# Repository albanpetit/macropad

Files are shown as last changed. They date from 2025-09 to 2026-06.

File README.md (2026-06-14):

# Makerpad

A fully open-source macropad built from scratch — custom PCB, 3D-printed enclosure, and embedded firmware. 20 programmable keys, two rotary encoders, a 2" color display driven by LVGL, and 22 addressable RGB LEDs, all running on an RP2040.

Everything is designed to be reproducible: order the PCB, print the case, flash the firmware, and configure your keymap via a JSON file.

---

## What's inside

| Directory | Description |
|---|---|
| [`ecad/`](ecad/README.md) | KiCad schematic + PCB, BOM, custom footprints |
| [`mcad/`](mcad/README.md) | STEP files for the enclosure |
| [`fw/`](fw/README.md) | PlatformIO firmware (C++, RP2040) |
| `doc/` | Datasheets, iBOM, schematic PDF |

---

## Hardware at a glance

| Component | Part |
|---|---|
| MCU | RP2040 (LQFN-56), 133 MHz, 264 KB RAM |
| Flash | W25Q128JVP — 16 MB SPI |
| Display | HS20HS072RX — 2" 240×320 ST7789V2-HSD SPI |
| RGB LEDs | WS2812B-2020 × 22 — addressable, 5V |
| Keys | 4 cols × 5 rows = 20 keys |
| Encoders | PEC12R-4225F-S0024 × 2 — 24 PPR + push |
| Connectivity | USB-C (HID keyboard + consumer control) |

---

## Roadmap

- [x] Layer switching via encoder
- [x] Volume control with speaker/mic toggle
- [ ] Macro sequence support
- [ ] Per-key LED color from config
- [ ] OTA config update via USB mass storage

---

## Contributing

See [CONTRIBUTING.md](CONTRIBUTING.md) for the commit convention, scope definitions, and contribution guidelines.

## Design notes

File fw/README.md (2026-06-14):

# Firmware

Built with [PlatformIO](https://platformio.org/) targeting the RP2040. Keys, layers and LED settings live in a JSON config file on LittleFS — no recompilation needed to remap keys.

---

## Getting started

```bash
pio run -e pico -t upload      # Flash firmware
pio run -e pico -t uploadfs    # Flash default config
pio device monitor -e pico     # Serial monitor (115200 baud)
```

---

## Key configuration

Config is stored in `data/config.json` and loaded from LittleFS at boot.

```json
{
  "brightness": 80,
  "active_layer": 0,
  "layers": [
    {
      "name": "Default",
      "color": [0, 100, 255],
      "keys": [
        { "type": "key",      "code": 4   },
        { "type": "consumer", "code": 233 },
        { "type": "key",      "code": 0   }
      ]
    }
  ]
}
```

Each layer holds 20 key definitions (row-major, 4 cols × 5 rows).

| Key type | Description |
|---|---|
| `key` | Standard HID keycode |
| `consumer` | Consumer control (media, volume) |
| `macro` | Sequence of keycodes *(planned)* |

---

## Controls

| Control | Action |
|---|---|
| Encoder 0 rotate | Navigate layers |
| Encoder 0 press | Activate selected layer |
| Encoder 1 rotate | Volume up/down |
| Encoder 1 press | Mute |
| Encoder 1 long press (600 ms) | Toggle speaker / mic mode |

---

## Architecture

```
fw/src/
├── main.cpp              # Entry point, main loop
├── lv_conf.h             # LVGL compile-time config
├── config/
│   ├── config.h          # Pin definitions, build constants
│   └── keymap.h          # KeyDef, Layer types + default keymap
├── hal/
│   ├── matrix.h/.cpp     # Key matrix scanning (4×5, debounce)
│   ├── encoder.h/.cpp    # Rotary encoder via interrupt
│   ├── leds.h/.cpp       # WS2812B via NeoPixel
│   └── display.h/.cpp    # ST7789V2-HSD driver + LVGL flush bridge
├── hid/
│   └── hid.h/.cpp        # USB HID (keyboard + consumer control)
├── storage/
│   └── storage.h/.cpp    # LittleFS + ArduinoJson config persistence
└── ui/
    └── ui.h/.cpp         # LVGL single-screen layer list
```

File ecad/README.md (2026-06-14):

# ECAD

PCB design for the Makerpad — schematic and layout done in [KiCad](https://www.kicad.org/).

---

## Files

| File / Directory | Description |
|---|---|
| `ecad.kicad_pro` | KiCad project root |
| `ecad.kicad_sch` | Top-level schematic |
| `switches.kicad_sch` | Key matrix sub-sheet |
| `leds.kicad_sch` | LED chain sub-sheet |
| `ecad.kicad_pcb` | PCB layout |
| `library.pretty/` | Custom footprints (RP2040, WS2812B-2020, encoders…) |
| `3d-models/` | STEP files for 3D preview |
| `ecad-backups/` | KiCad auto-backups |

Exported outputs live in `doc/`:

| Output | Description |
|---|---|
| `doc/bom.xlsx` / `bom.pdf` | Bill of materials |
| `doc/schematic.pdf` | Full schematic PDF |
| `doc/ibom/ibom.html` | Interactive BOM (open in browser) |
| `doc/ecad-export/` | Gerbers and drill files |
| `doc/datasheet/` | Datasheets for key components |

---

## Opening the project

```bash
kicad ecad.kicad_pro
```

Requires KiCad 8 or later. All symbols and footprints are embedded or resolved via `sym-lib-table` and `fp-lib-table` — no external library setup needed.

---

## Interactive BOM

Open `doc/ibom/ibom.html` in any browser. Click a component to highlight its position on the board — useful when soldering.

---

## Ordering the PCB

1. Use the Gerbers in `doc/ecad-export/` and upload them to your preferred fabricator (JLCPCB, PCBWay, OSHPark…).
2. Recommended specs: 2-layer, 1.6 mm FR4, HASL or ENIG finish, 0.2 mm min trace/space.
3. Cross-reference the BOM (`doc/bom.xlsx`) for part numbers and quantities.

---

## Custom footprints (`library.pretty/`)

| Footprint | Component |
|---|---|
| `QFN-56-1EP_7x7mm_P0.4mm` | RP2040 |
| `LED_WS2812B-2020_PLCC4_2.0x2.0mm` | WS2812B-2020 RGB LED |
| `Crystal_SMD_Abracon_ABM8G-4Pin_3.2x2.5mm` | 12 MHz crystal |
| `Hirose_FH12-12S-0.5SH` | 0.5 mm FPC connector (display) |
| `PinHeader_2x05_P1.27mm_Vertical_SMD` | SWD debug header |

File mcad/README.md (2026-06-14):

# MCAD

3D models for the Makerpad enclosure, exported as STEP files.

---

## Files

| File | Description |
|---|---|
| `ecad.step` | Full PCB assembly export from KiCad |
| `kailh-switch.step` | Kailh low-profile key switch model |

---

## Usage

Both files are standard STEP (ISO 10303) and open in any CAD tool: FreeCAD, Fusion 360, SolidWorks, or directly in KiCad's 3D viewer.

To preview the full board assembly in KiCad:

1. Open `ecad/ecad.kicad_pcb`
2. Go to **View → 3D Viewer**
3. STEP models are resolved automatically from `ecad/3d-models/`

---

## Printing the enclosure

If you design a custom case around `ecad.step`:

- PCB dimensions and mounting hole positions are embedded in the STEP file
- Mounting holes: M2 (2.2 mm) and M3 (3.2 mm) — see `ecad/library.pretty/` for exact footprints
- Leave clearance for the USB-C connector, display FPC, and encoder shafts on the top face

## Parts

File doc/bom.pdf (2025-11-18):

### Electronic BOM

Reference | Qty | Value | Mrf# | LCSC part # | Footprint | Datasheet
C1,C2,C3,C12 | 4 | 1u | GRM155R61H105KE05D | C1518208 | Capacitor_SMD:C_0402_1005Metric | ~
C4,C5,C6,C7,C8,C10,C11,C13,C14,C17 | 10 | 100n | GRM155R71H104KE14D | C77020 | Capacitor_SMD:C_0402_1005Metric | ~
C9 | 1 | 4.7u | GCM1555C1H4R7CA16J | C2191748 | Capacitor_SMD:C_0402_1005Metric | ~
C15,C16 | 2 | 15p | GJM1555C1H150FB01D | C441742 | Capacitor_SMD:C_0402_1005Metric | ~
C18,C19 | 2 | 0.1u | | C77020 | Capacitor_SMD:C_0402_1005Metric | ~
D1,D2,D3,D4,D5,D6,D7,D8,D9,D10,D11, D12,D33,D34,D35,D36,D37,D38,D39,D4 0 | 20 | 1N4148W | 1N4148W-E3-08 | C241939 | Diode_SMD:D_SOD-123 | ~
D13,D14,D17,D18,D19,D21,D22,D23,D2 5,D26,D27,D29,D30,D31,D32,D41,D42, D43,D45,D46,D47,D48 | 22 | WS2812B-2020 | WS2812B-2020 | C965555 | LED_SMD:LED_WS2812B-2020_PLCC4_2.0x2.0mm | https://cdn-shop.adafruit.com/product-files/4684/4684_WS2812B-2020_V1.3_EN.pdf
H1,H2,H3,H4 | 4 | MountingHole | SMTSO3030CTJ | C2915308 | Mounting_Wuerth:Mounting_Wuerth_WA-SMSI-M3_H4mm_9774040360 | ~
H5,H10,H11,H12 | 4 | MountingHole | | ~ | MountingHole:MountingHole_3.2mm_M3_DIN965 | ~
H6,H7,H8,H9 | 4 | MountingHole | | ~ | MountingHole:MountingHole_2.2mm_M2_DIN965 | ~
J1 | 1 | JTAG | HX PZ1.27-2x5P TP | C41376037 | Connector_PinHeader_1.27mm:PinHeader_2x05_P1.27mm_Vertical_SMD | http://infocenter.arm.com/help/topic/com.arm.doc.ddi0314h/DDI0314H_coresight_components_trm.pdf
J2 | 1 | USB_C | 12401948E412A | C3197899 | Connector_USB:USB_C_Receptacle_Amphenol_12401948E412A | https://www.usb.org/sites/default/files/documents/usb_type-c.zip
J3 | 1 | Display | FH12-12S-0.5SH(55) | C88360 | Connector_FFC-FPC:Hirose_FH12-12S-0.5SH_1x12-1MP_P0.50mm_Horizontal | ~
Q2 | 1 | SS8050 | SS8050 | C2914407 | Package_TO_SOT_SMD:SOT-23 | http://www.secosgmbh.com/datasheet/products/SSMPTransistor/SOT-23/SS8050.pdf
R1,R4,R13 | 3 | 10k | RC0402FR-0710KL | C60490 | Resistor_SMD:R_0402_1005Metric | ~
R2,R3,R5,R6 | 4 | 27,4 | RC0402FR-0727R4L | C274349 | Resistor_SMD:R_0402_1005Metric | ~
R7 | 1 | 33 | RC0402FR-0733RL | C138002 | Resistor_SMD:R_0402_1005Metric | ~
R11 | 1 | 10 | AC0402FR-0710RL | C144805 | Resistor_SMD:R_0402_1005Metric | ~
R12 | 1 | 1k | RC0402FR-071KL | C106235 | Resistor_SMD:R_0402_1005Metric | ~
SW1,SW2,SW3,SW4,SW5,SW6,SW7,S W8,SW9,SW12,SW13,SW14,SW16,SW1 7,SW18,SW19,SW20,SW21,SW22,SW23 | 20 | Kailh choc v2 | | | PCM_Switch_Keyboard_Hotswap_Kailh:SW_Hotswap_Kailh_Choc_V2 | ~
DISPLAY | 1 | HS HS20HS072RX | HS20HS072RX | C5329582
SW10,SW11 | 2 | RotaryEncoder_Switch | PEC12R-4225F-S0024 | C18164805 | Rotary_Encoder:RotaryEncoder_Bourns_Vertical_PEC12R-3x17F-Sxxxx | ~
SW15 | 1 | RESET | KMR223GLFG | C221678 | Button_Switch_SMD:SW_Push_1P1T_NO_CK_KMR2 | ~
SW24,SW25 | 2 | | SH-6X6X5.5H-CJ | C42416244 | Button_Switch_THT:SW_PUSH_6mm | ~
U1 | 1 | AP2112K-3.3 | AP2112K-3.3TRG1 | C51118 | Package_TO_SOT_SMD:SOT-23-5 | https://www.diodes.com/assets/Datasheets/AP2112.pdf
U2 | 1 | RP2040 | RP2040 | C2040 | Package_DFN_QFN:QFN-56-1EP_7x7mm_P0.4mm_EP3.2x3.2mm | https://datasheets.raspberrypi.com/rp2040/rp2040-datasheet.pdf
U4 | 1 | SN74LV1T34DBV | SN74LV1T34DBVR | C100024 | Package_TO_SOT_SMD:SOT-23-5 | https://www.ti.com/lit/ds/symlink/sn74lv1t34.pdf
U5 | 1 | W25Q128JVP | W25Q128JVPIQ | C190862 | Package_SON:WSON-8-1EP_6x5mm_P1.27mm_EP3.4x4.3mm | https://www.winbond.com/resource-files/w25q128jv_dtr%20revc%2003272018%20plus.pdf
Y1 | 1 | 12MHz | ABM8-272-T3 | C20625731 | Crystal:Crystal_SMD_Abracon_ABM8AIG-4Pin_3.2x2.5mm | ~

1

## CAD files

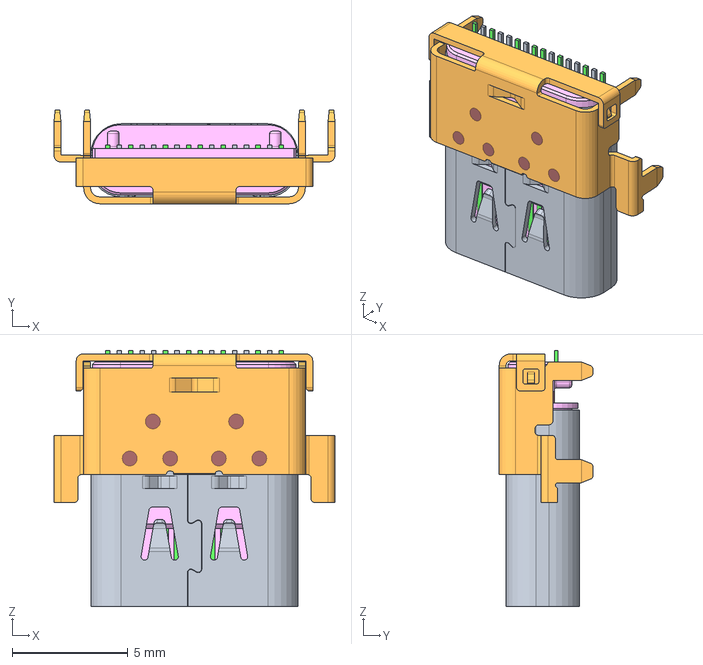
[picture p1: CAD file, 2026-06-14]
ecad/3d-models/amphenol-12401948E412A.step
12.1 x 4.05 x 11.1 mm

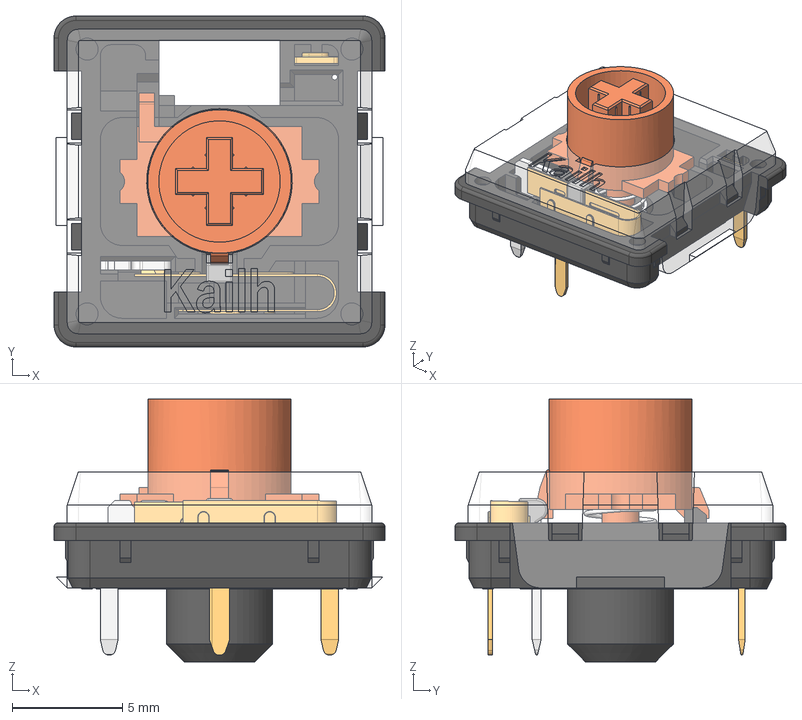
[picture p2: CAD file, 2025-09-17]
mcad/kailh-switch.step
15.0 x 15.0 x 11.9 mm
bottom
contact
pin1
stem
top
pin2
pin3
shrunken_spring

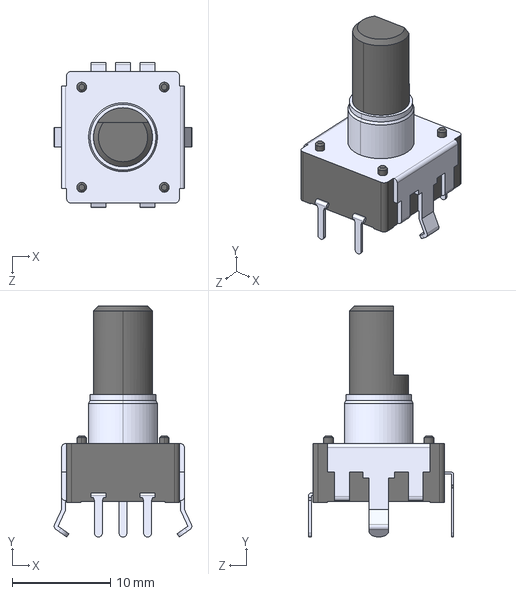
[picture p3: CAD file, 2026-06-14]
ecad/3d-models/bourns-PEC12R-4225F-S0024.stp
14.0 x 23.5 x 14.7 mm

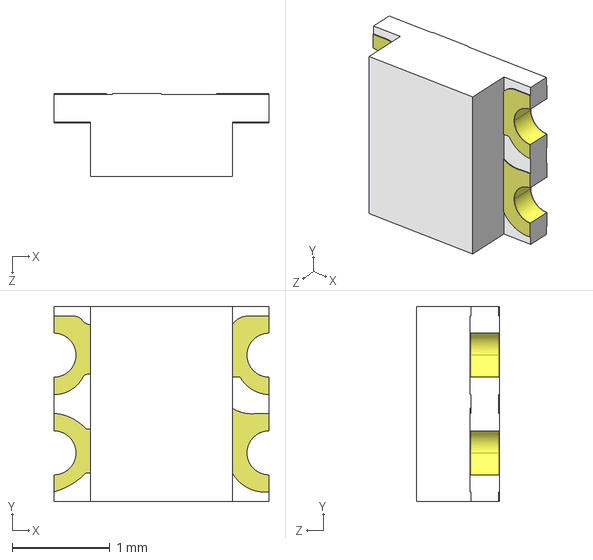
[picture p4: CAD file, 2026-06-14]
ecad/3d-models/worldsemi-WS2812-2020.step
2.20 x 2.00 x 0.85 mm

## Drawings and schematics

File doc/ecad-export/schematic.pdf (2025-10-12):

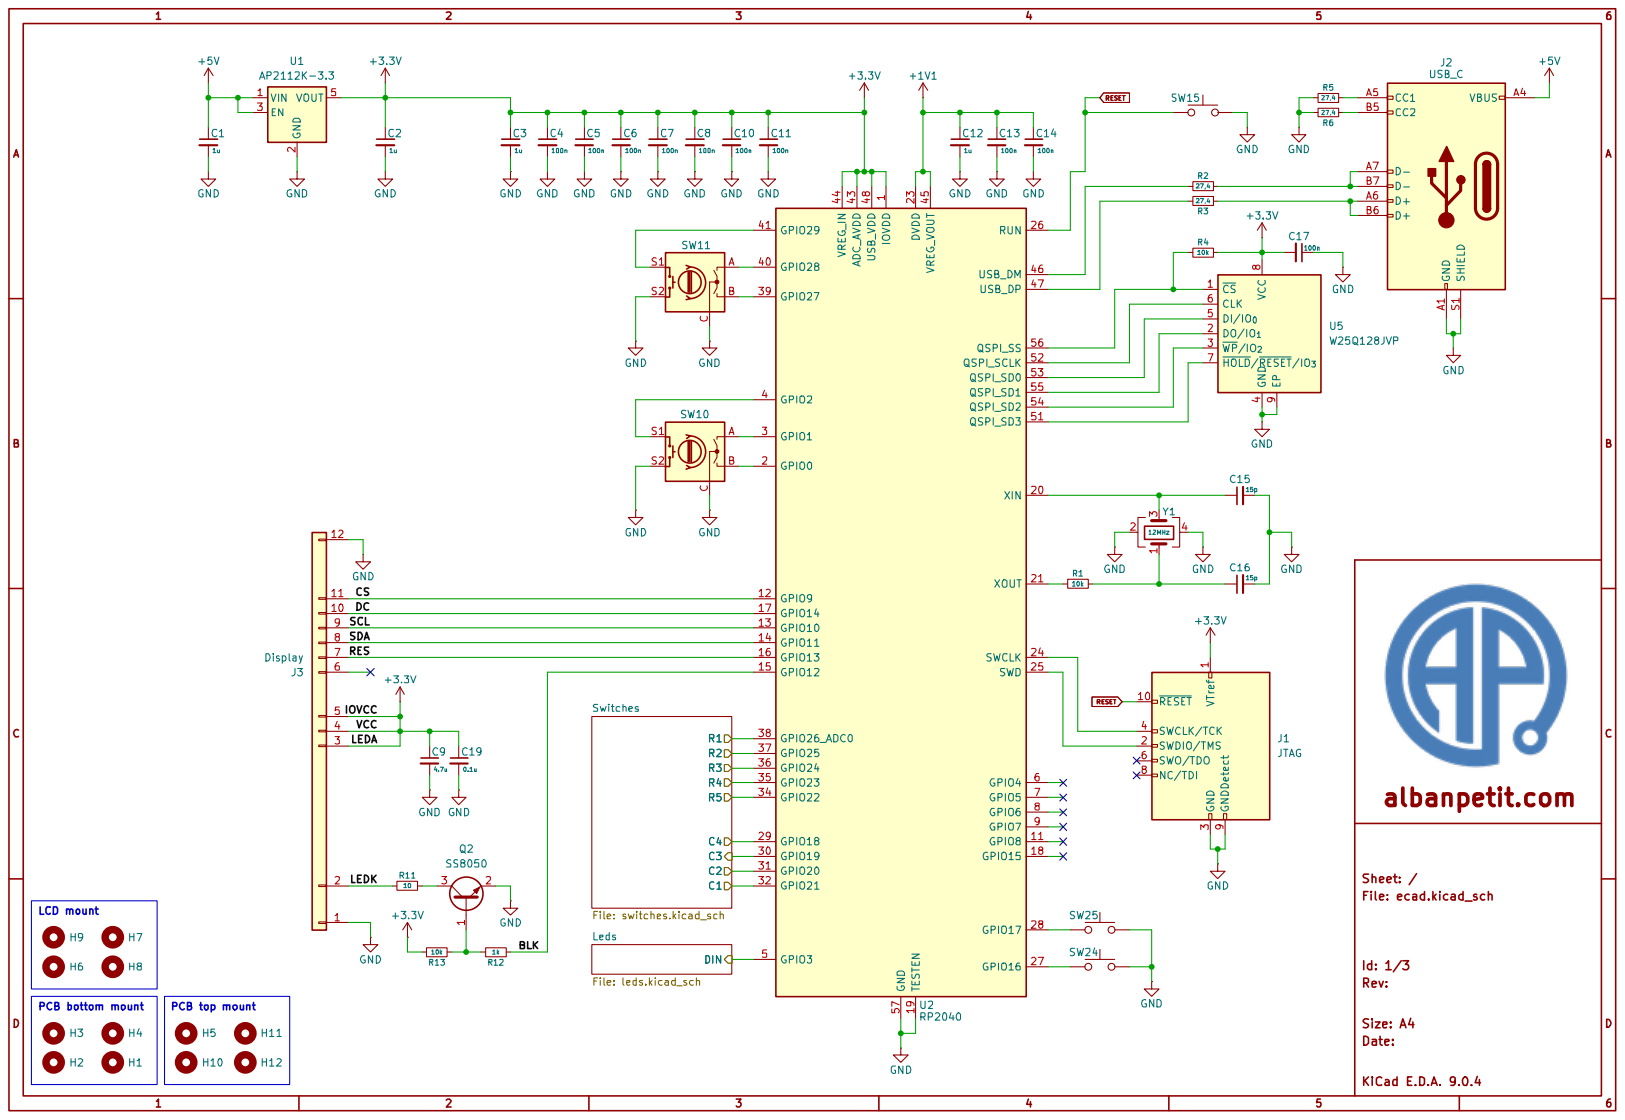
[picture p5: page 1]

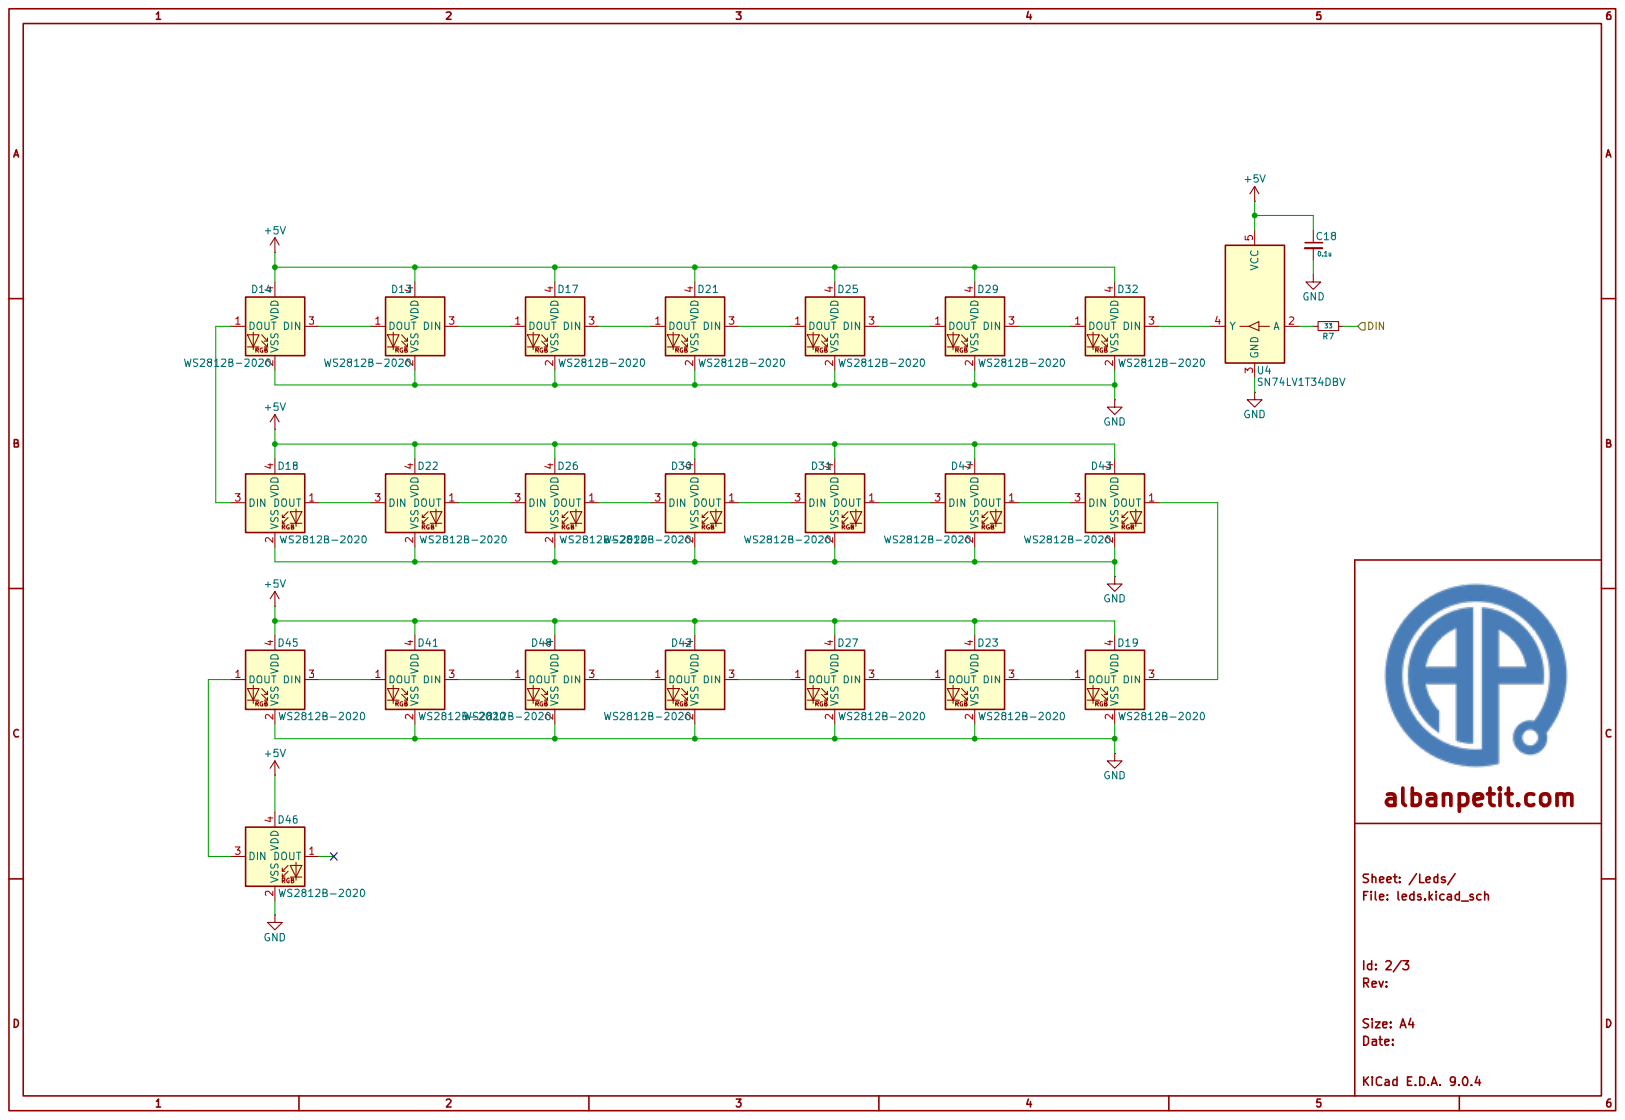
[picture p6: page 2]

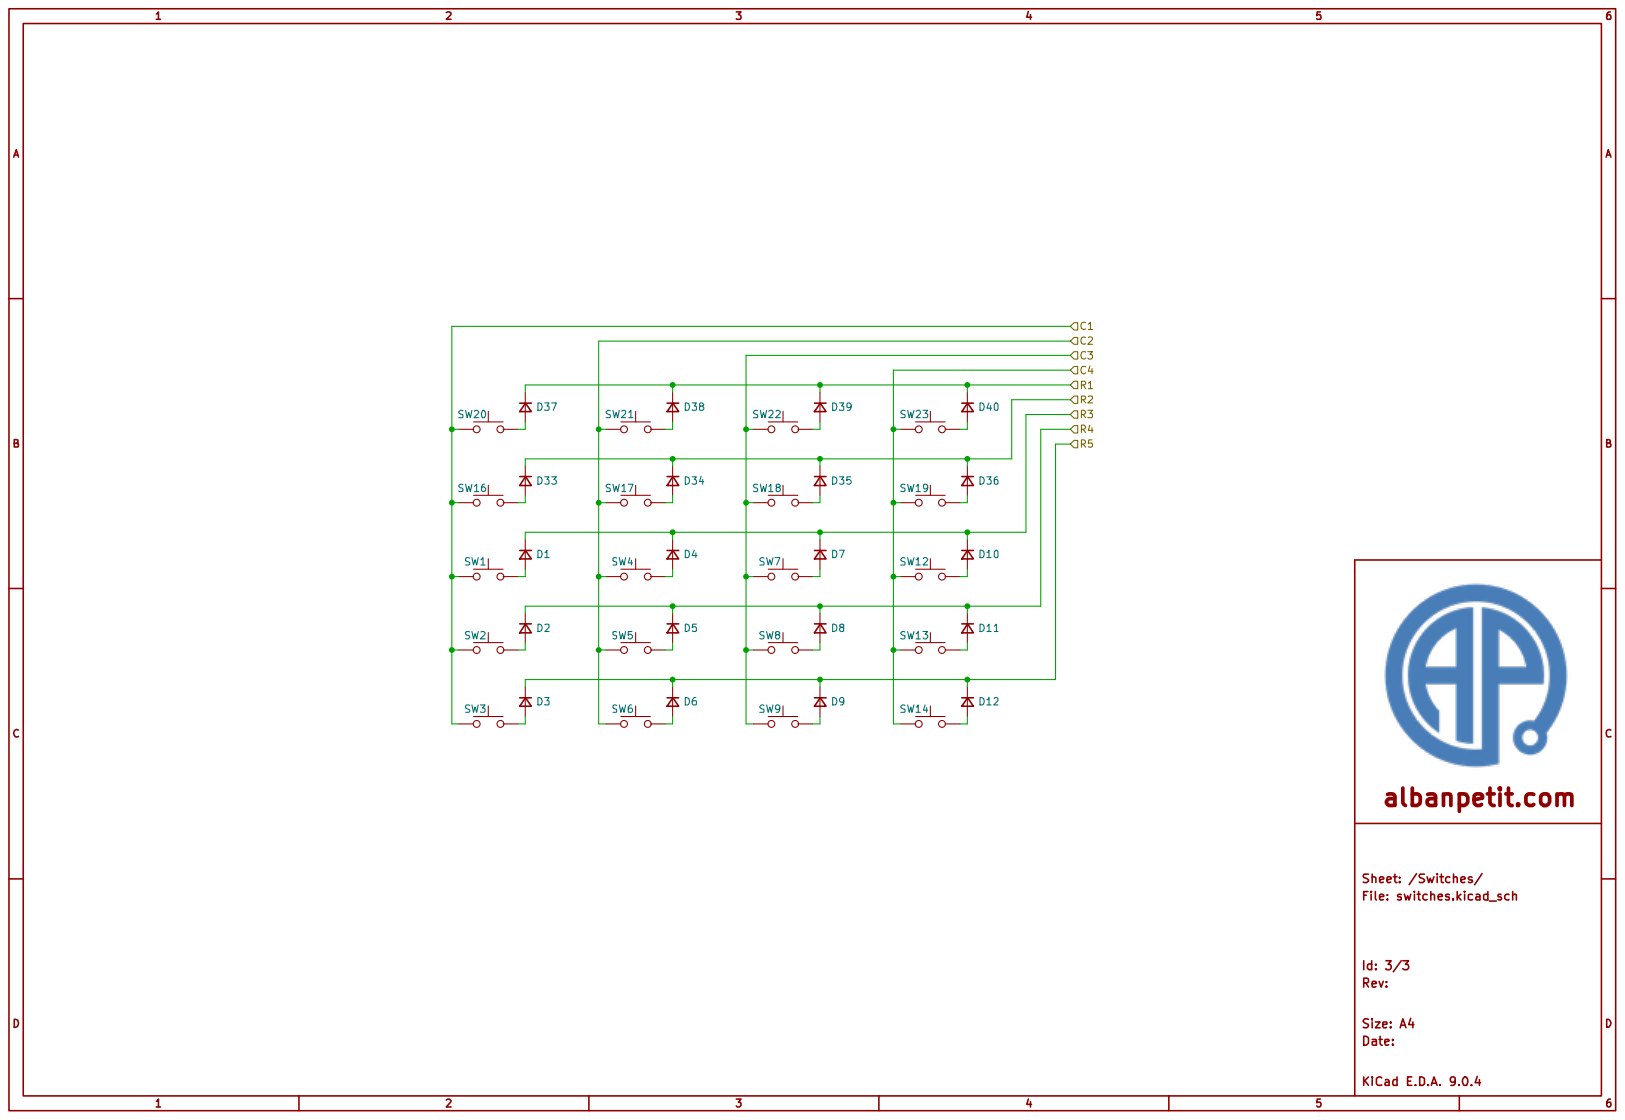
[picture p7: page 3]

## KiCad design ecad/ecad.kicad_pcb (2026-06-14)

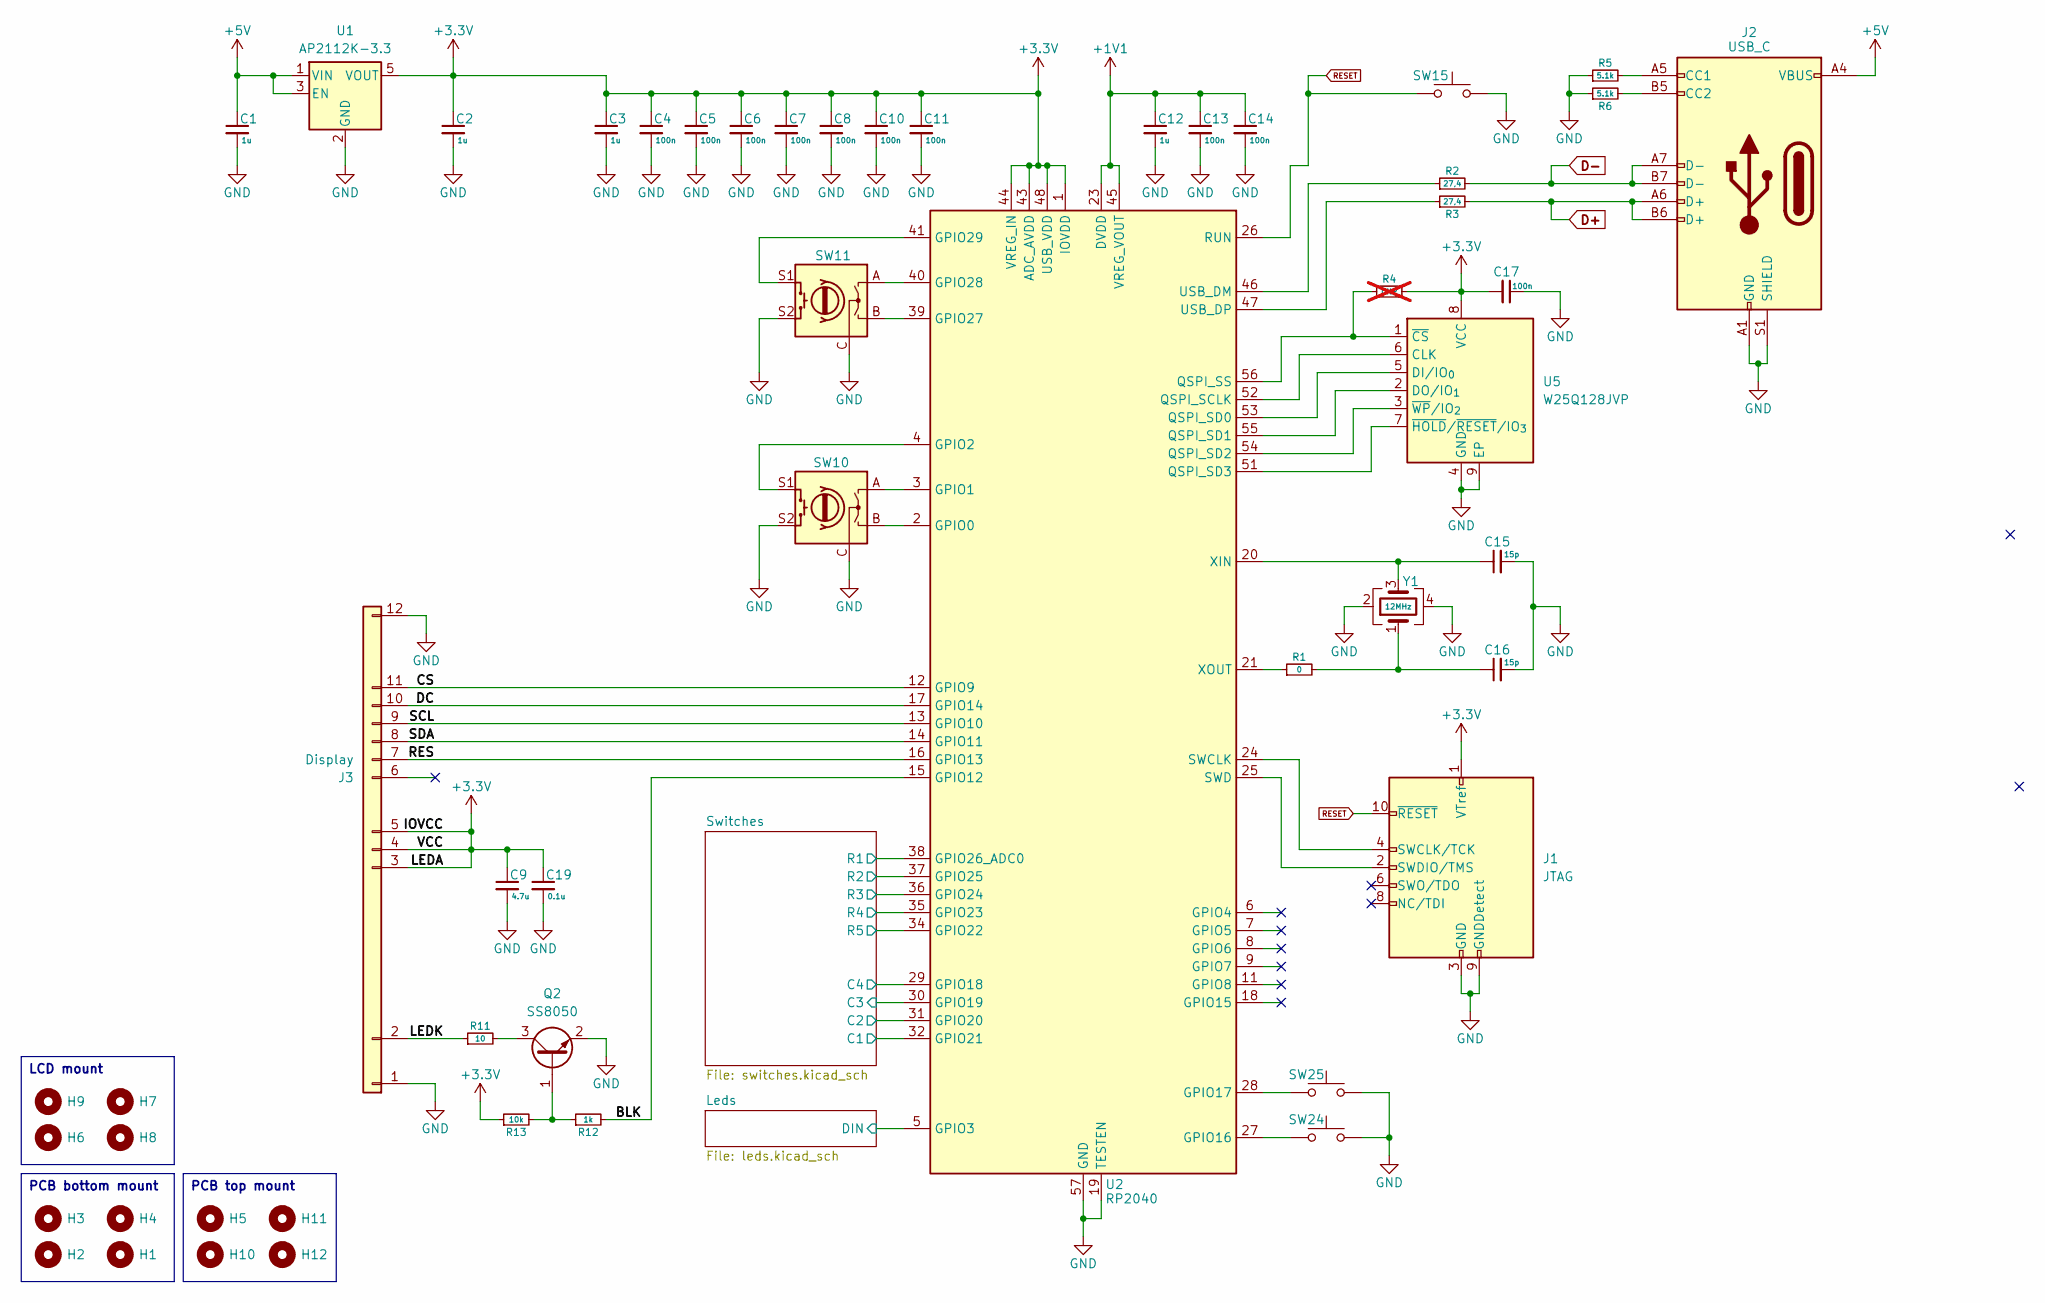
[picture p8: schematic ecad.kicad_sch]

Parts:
C1, C2, C3, C12: 1u; C_0402_1005Metric
C4, C5, C6, C7, C8, C10, C11, C13, C14, C17: 100n; C_0402_1005Metric
C9: 4.7u; C_0402_1005Metric
C15, C16: 15p; C_0402_1005Metric
C19: 0.1u; C_0402_1005Metric
H1, H2, H3, H4: MountingHole; smtso3030ctj
H5, H10, H11, H12: MountingHole; MountingHole_3.2mm_M3_DIN965
H6, H7, H8, H9: MountingHole; MountingHole_2.2mm_M2_DIN965
J1: JTAG; PinHeader_2x05_P1.27mm_Vertical_SMD
J2: USB_C; USB_C_Receptacle_Amphenol_12401948E412A
J3: Display; Hirose_FH12-12S-0.5SH_1x12-1MP_P0.50mm_Horizontal
Q2: SS8050; SOT-23
R1: 0; R_0402_1005Metric
R2, R3: 27,4; R_0402_1005Metric
R4: DNP; R_0402_1005Metric; not fitted
R5, R6: 5.1k; R_0402_1005Metric
R11: 10; R_0402_1005Metric
R12: 1k; R_0402_1005Metric
R13: 10k; R_0402_1005Metric
SW10, SW11: RotaryEncoder_Switch; RotaryEncoder_Bourns_Vertical_PEC12R-3x17F-Sxxxx
SW15: RESET; SW_Push_1P1T_NO_CK_KMR2
SW24, SW25: SW_PUSH_6mm
U1: AP2112K-3.3; SOT-23-5
U2: RP2040; QFN-56-1EP_7x7mm_P0.4mm_EP3.2x3.2mm
U5: W25Q128JVP; WSON-8-1EP_6x5mm_P1.27mm_EP3.4x4.3mm
Y1: 12MHz; Crystal_SMD_Abracon_ABM8G-4Pin_3.2x2.5mm

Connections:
+1V1: C12.1, C13.1, C14.1, U2.23 (DVDD), U2.45 (VREG_VOUT), U2.50 (DVDD)
+3.3V: C2.1, C3.1, C4.1, C5.1, C6.1, C7.1, C8.1, C9.1, C10.1, C11.1, C17.2, C19.1, J1.1 (VTref), J3.3, J3.4, J3.5, R4.2, R13.1, U1.5 (VOUT), U2.1 (IOVDD), U2.10 (IOVDD), U2.22 (IOVDD), U2.33 (IOVDD), U2.42 (IOVDD), U2.43 (ADC_AVDD), U2.44 (VREG_IN), U2.48 (USB_VDD), U2.49 (IOVDD), U5.8 (VCC)
+5V: C1.1, J2.A4 (VBUS), J2.A9 (VBUS), J2.B4 (VBUS), J2.B9 (VBUS), U1.1 (VIN), U1.3 (EN); also elsewhere on the board
/BLK: R12.2, U2.15 (GPIO12)
/CS: J3.11, U2.12 (GPIO9)
/DC: J3.10, U2.17 (GPIO14)
/LEDK: J3.2, R11.1
/Leds/DIN: U2.5 (GPIO3); also elsewhere on the board
/RES: J3.7, U2.16 (GPIO13)
/SCL: J3.9, U2.13 (GPIO10)
/SDA: J3.8, U2.14 (GPIO11)
/Switches/C1: U2.32 (GPIO21); also elsewhere on the board
/Switches/C2: U2.31 (GPIO20); also elsewhere on the board
/Switches/C3: U2.30 (GPIO19); also elsewhere on the board
/Switches/C4: U2.29 (GPIO18); also elsewhere on the board
/Switches/R1: U2.38 (GPIO26_ADC0); also elsewhere on the board
/Switches/R2: U2.37 (GPIO25); also elsewhere on the board
/Switches/R3: U2.36 (GPIO24); also elsewhere on the board
/Switches/R4: U2.35 (GPIO23); also elsewhere on the board
/Switches/R5: U2.34 (GPIO22); also elsewhere on the board
D+: J2.A6 (D+), J2.B6 (D+), R3.2
D-: J2.A7 (D-), J2.B7 (D-), R2.2
GND: C1.2, C2.2, C3.2, C4.2, C5.2, C6.2, C7.2, C8.2, C9.2, C10.2, C11.2, C12.2, C13.2, C14.2, C15.2, C16.2, C17.1, C19.2, J1.3 (GND), J1.5 (GND), J1.9 (GNDDetect), J2.A1 (GND), J2.A12 (GND), J2.B1 (GND), J2.B12 (GND), J2.S1 (SHIELD), J3.1, J3.12, Q2.2 (E), R5.1, R6.1, SW10.C, SW10.S2, SW11.C, SW11.S2, SW15.2, SW24.2, SW25.2, U1.2 (GND), U2.19 (TESTEN), U2.57 (GND), U5.4 (GND), U5.9 (EP), Y1.2, Y1.4; also elsewhere on the board
unnamed: C16.1, R1.2, Y1.1
unnamed: J1.4 (SWCLK/TCK), U2.24 (SWCLK)
unnamed: J1.2 (SWDIO/TMS), U2.25 (SWD)
unnamed: J2.A5 (CC1), R5.2
unnamed: J2.B5 (CC2), R6.2
unnamed: Q2.1 (B), R12.1, R13.2
unnamed: Q2.3 (C), R11.2
unnamed: SW10.B, U2.2 (GPIO0)
unnamed: SW10.A, U2.3 (GPIO1)
unnamed: SW10.S1, U2.4 (GPIO2)
unnamed: SW24.1, U2.27 (GPIO16)
unnamed: SW25.1, U2.28 (GPIO17)
unnamed: SW11.B, U2.39 (GPIO27)
unnamed: SW11.A, U2.40 (GPIO28)
unnamed: SW11.S1, U2.41 (GPIO29)
unnamed: U2.52 (QSPI_SCLK), U5.6 (CLK)
unnamed: U2.53 (QSPI_SD0), U5.5 (DI/IO_{0})
unnamed: U2.55 (QSPI_SD1), U5.2 (DO/IO_{1})
unnamed: U2.54 (QSPI_SD2), U5.3 (~WP/IO_{2})
unnamed: U2.51 (QSPI_SD3), U5.7 (~HOLD/~RESET/IO_{3})
unnamed: R4.1, U2.56 (QSPI_SS), U5.1 (~CS)
unnamed: R2.1, U2.46 (USB_DM)
unnamed: R3.1, U2.47 (USB_DP)
unnamed: C15.1, U2.20 (XIN), Y1.3
unnamed: R1.1, U2.21 (XOUT)
RESET: J1.10 (~RESET), SW15.1, U2.26 (RUN)

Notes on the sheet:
LCD mount
PCB bottom mount
PCB top mount

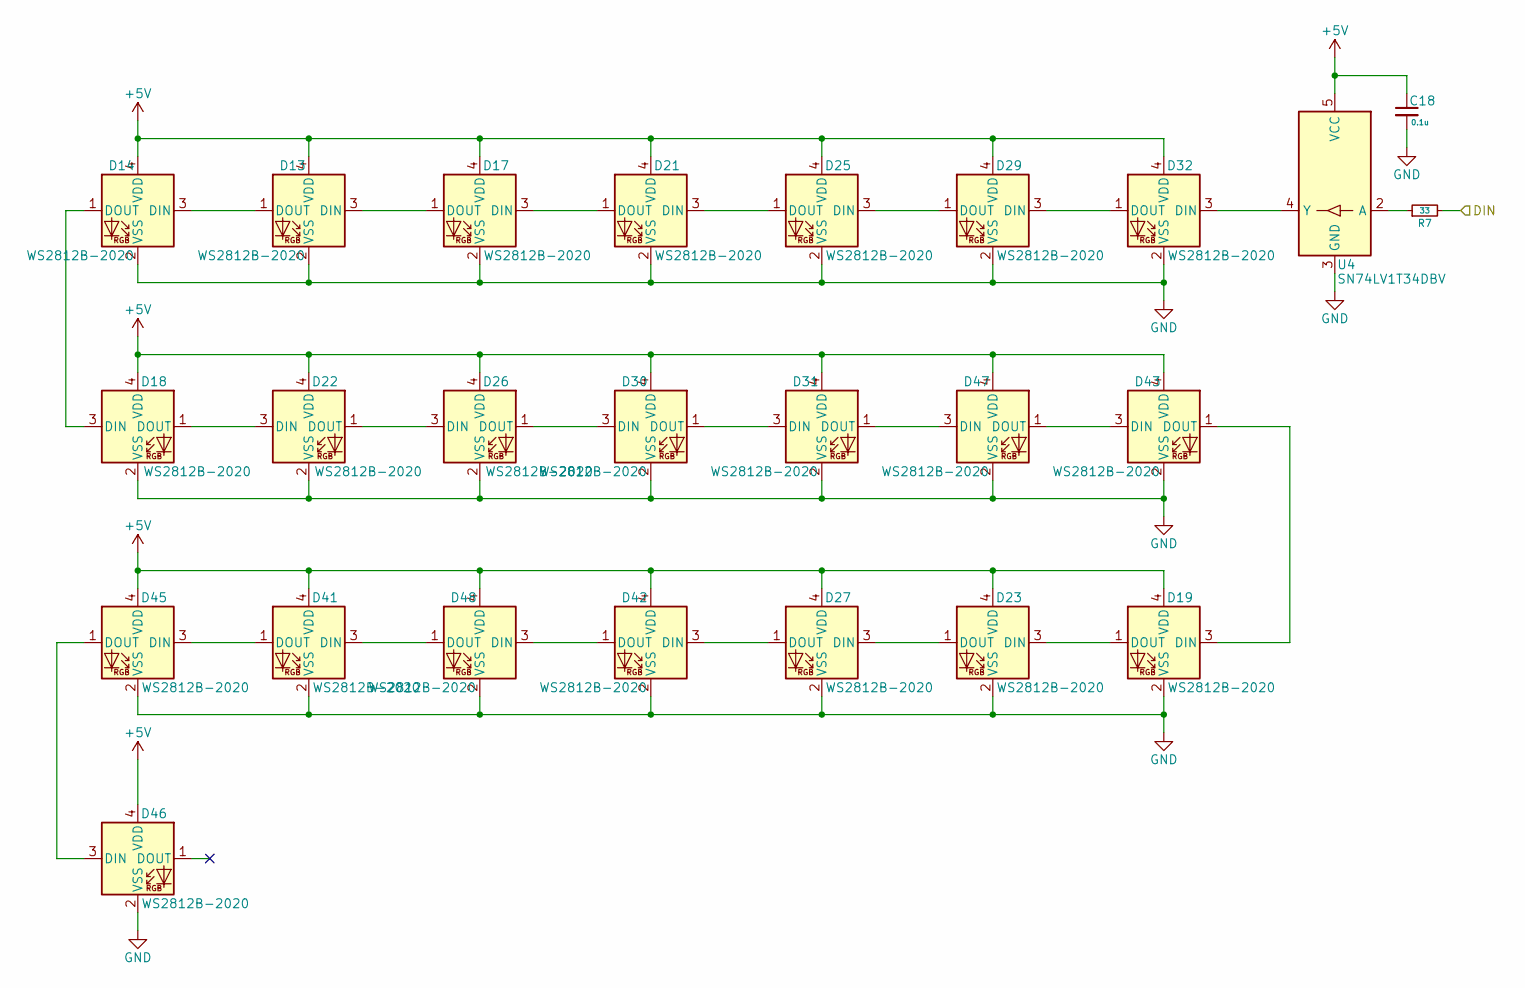
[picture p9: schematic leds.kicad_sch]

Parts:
C18: 0.1u; C_0402_1005Metric
D13, D14, D17, D18, D19, D21, D22, D23, D25, D26, D27, D29, D30, D31, D32, D41, D42, D43, D45, D46, D47, D48: WS2812B-2020; LED_WS2812B-2020_PLCC4_2.0x2.0mm
R7: 33; R_0402_1005Metric
U4: SN74LV1T34DBV; SOT-23-5

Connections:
+5V: C18.1, D13.4 (VDD), D14.4 (VDD), D17.4 (VDD), D18.4 (VDD), D19.4 (VDD), D21.4 (VDD), D22.4 (VDD), D23.4 (VDD), D25.4 (VDD), D26.4 (VDD), D27.4 (VDD), D29.4 (VDD), D30.4 (VDD), D31.4 (VDD), D32.4 (VDD), D41.4 (VDD), D42.4 (VDD), D43.4 (VDD), D45.4 (VDD), D46.4 (VDD), D47.4 (VDD), D48.4 (VDD), U4.5 (VCC); also elsewhere on the board
/Leds/DIN: R7.2; also elsewhere on the board
GND: C18.2, D13.2 (VSS), D14.2 (VSS), D17.2 (VSS), D18.2 (VSS), D19.2 (VSS), D21.2 (VSS), D22.2 (VSS), D23.2 (VSS), D25.2 (VSS), D26.2 (VSS), D27.2 (VSS), D29.2 (VSS), D30.2 (VSS), D31.2 (VSS), D32.2 (VSS), D41.2 (VSS), D42.2 (VSS), D43.2 (VSS), D45.2 (VSS), D46.2 (VSS), D47.2 (VSS), D48.2 (VSS), U4.3 (GND); also elsewhere on the board
unnamed: D13.3 (DIN), D17.1 (DOUT)
unnamed: D13.1 (DOUT), D14.3 (DIN)
unnamed: D14.1 (DOUT), D18.3 (DIN)
unnamed: D17.3 (DIN), D21.1 (DOUT)
unnamed: D18.1 (DOUT), D22.3 (DIN)
unnamed: D19.3 (DIN), D43.1 (DOUT)
unnamed: D19.1 (DOUT), D23.3 (DIN)
unnamed: D21.3 (DIN), D25.1 (DOUT)
unnamed: D22.1 (DOUT), D26.3 (DIN)
unnamed: D23.1 (DOUT), D27.3 (DIN)
unnamed: D25.3 (DIN), D29.1 (DOUT)
unnamed: D26.1 (DOUT), D30.3 (DIN)
unnamed: D27.1 (DOUT), D42.3 (DIN)
unnamed: D29.3 (DIN), D32.1 (DOUT)
unnamed: D30.1 (DOUT), D31.3 (DIN)
unnamed: D31.1 (DOUT), D47.3 (DIN)
unnamed: D32.3 (DIN), U4.4 (Y)
unnamed: D41.3 (DIN), D48.1 (DOUT)
unnamed: D41.1 (DOUT), D45.3 (DIN)
unnamed: D42.1 (DOUT), D48.3 (DIN)
unnamed: D43.3 (DIN), D47.1 (DOUT)
unnamed: D45.1 (DOUT), D46.3 (DIN)
unnamed: R7.1, U4.2 (A)

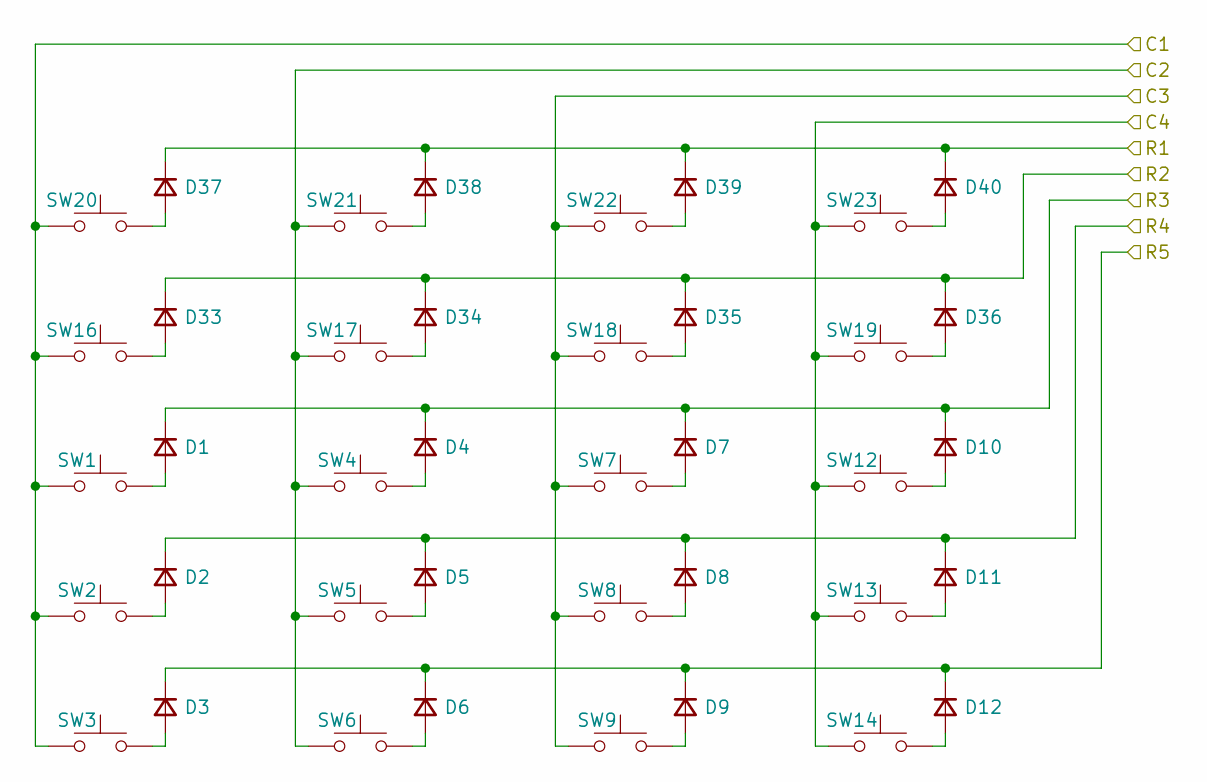
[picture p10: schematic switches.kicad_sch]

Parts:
D1, D2, D3, D4, D5, D6, D7, D8, D9, D10, D11, D12, D33, D34, D35, D36, D37, D38, D39, D40: 1N4148W; D_SOD-123
SW1, SW2, SW3, SW4, SW5, SW6, SW7, SW8, SW9, SW12, SW13, SW14, SW16, SW17, SW18, SW19, SW20, SW21, SW22, SW23: Kailh choc v2; SW_Hotswap_Kailh_Choc_V2

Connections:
/Switches/C1: SW1.1, SW2.1, SW3.1, SW16.1, SW20.1; also elsewhere on the board
/Switches/C2: SW4.1, SW5.1, SW6.1, SW17.1, SW21.1; also elsewhere on the board
/Switches/C3: SW7.1, SW8.1, SW9.1, SW18.1, SW22.1; also elsewhere on the board
/Switches/C4: SW12.1, SW13.1, SW14.1, SW19.1, SW23.1; also elsewhere on the board
/Switches/R1: D37.1 (K), D38.1 (K), D39.1 (K), D40.1 (K); also elsewhere on the board
/Switches/R2: D33.1 (K), D34.1 (K), D35.1 (K), D36.1 (K); also elsewhere on the board
/Switches/R3: D1.1 (K), D4.1 (K), D7.1 (K), D10.1 (K); also elsewhere on the board
/Switches/R4: D2.1 (K), D5.1 (K), D8.1 (K), D11.1 (K); also elsewhere on the board
/Switches/R5: D3.1 (K), D6.1 (K), D9.1 (K), D12.1 (K); also elsewhere on the board
unnamed: D1.2 (A), SW1.2
unnamed: D2.2 (A), SW2.2
unnamed: D3.2 (A), SW3.2
unnamed: D4.2 (A), SW4.2
unnamed: D5.2 (A), SW5.2
unnamed: D6.2 (A), SW6.2
unnamed: D7.2 (A), SW7.2
unnamed: D8.2 (A), SW8.2
unnamed: D9.2 (A), SW9.2
unnamed: D10.2 (A), SW12.2
unnamed: D11.2 (A), SW13.2
unnamed: D12.2 (A), SW14.2
unnamed: D33.2 (A), SW16.2
unnamed: D34.2 (A), SW17.2
unnamed: D35.2 (A), SW18.2
unnamed: D36.2 (A), SW19.2
unnamed: D37.2 (A), SW20.2
unnamed: D38.2 (A), SW21.2
unnamed: D39.2 (A), SW22.2
unnamed: D40.2 (A), SW23.2

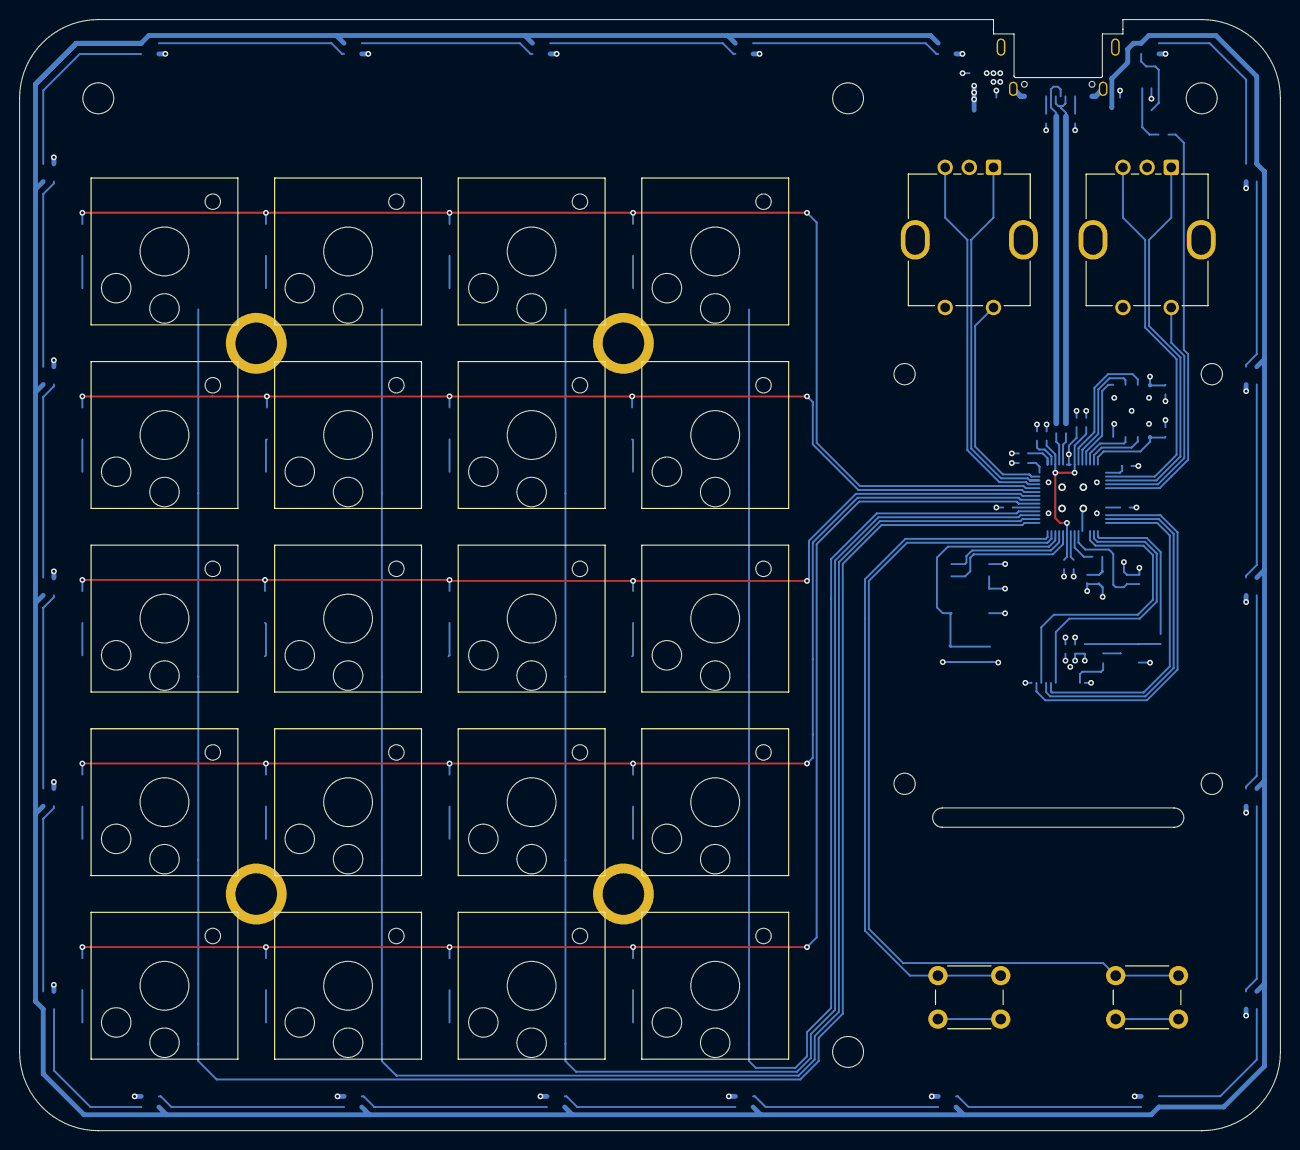
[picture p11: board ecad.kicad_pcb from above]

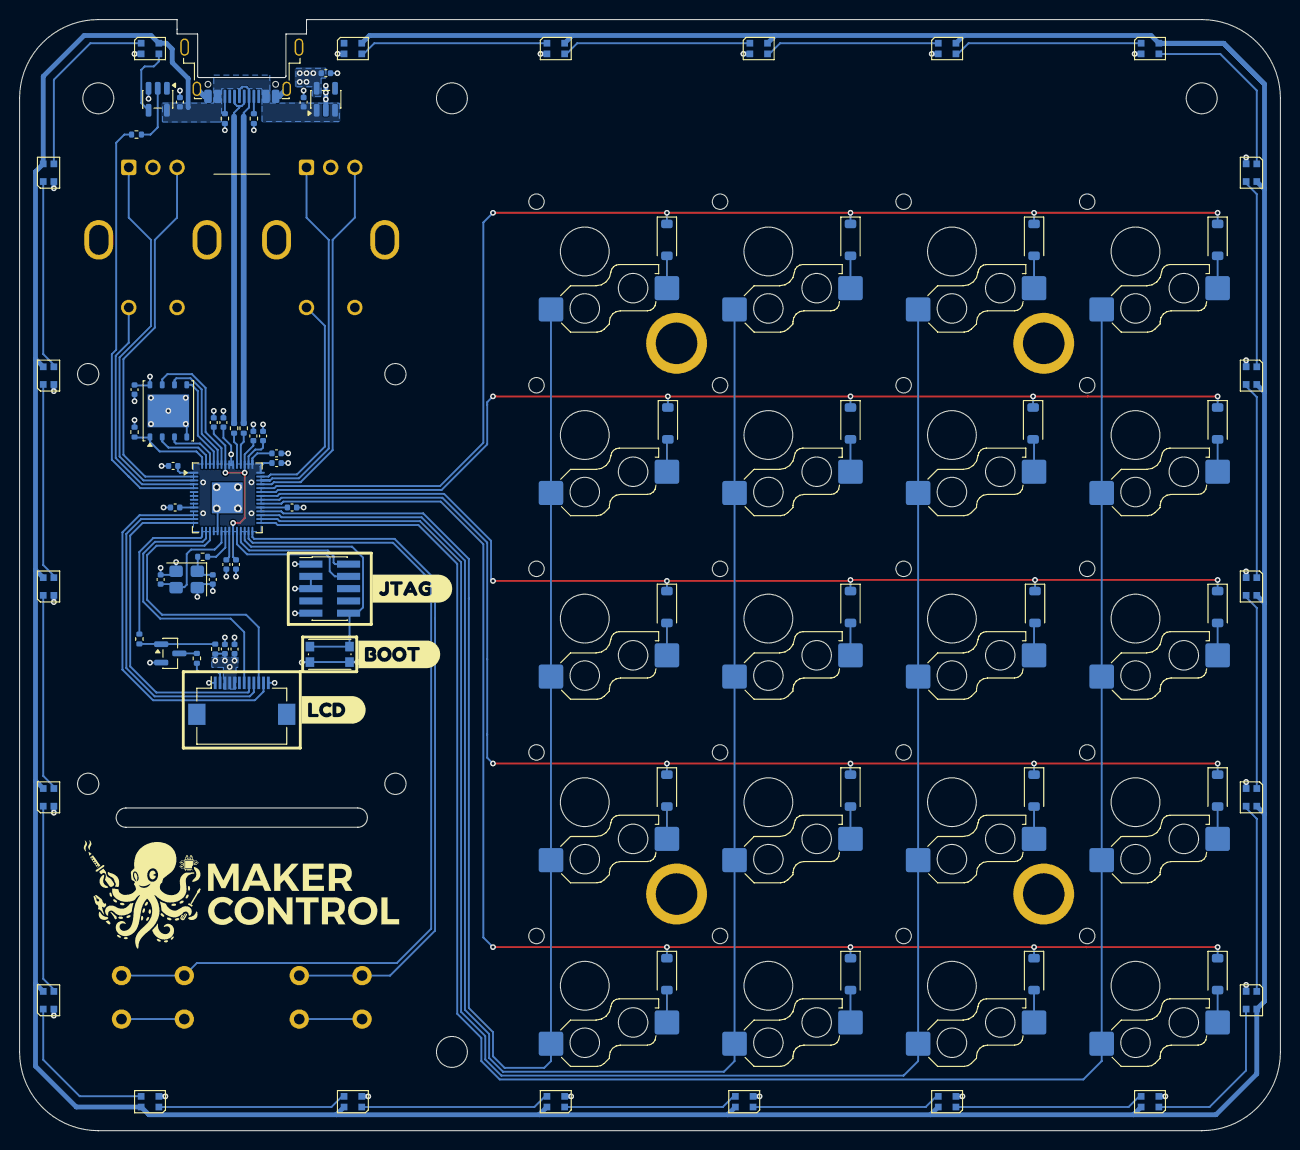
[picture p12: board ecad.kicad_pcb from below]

Board: 4 copper layers, 130.5 x 115.0 mm, 120 parts (88 on the bottom side), 92 nets.

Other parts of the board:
kibuzzard-68D988DF: G***; kibuzzard-68D988DF
kibuzzard-68D9895D: G***; kibuzzard-68D9895D
kibuzzard-68D98929: G***; kibuzzard-68D98929

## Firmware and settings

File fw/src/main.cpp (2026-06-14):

#include <Arduino.h>
#include <Keyboard.h>
#include <lvgl.h>

#include "config/config.h"
#include "hal/matrix.h"
#include "hal/encoder.h"
#include "hal/leds.h"
#include "hal/display.h"
#include "hid/hid.h"
#include "storage/storage.h"
#include "ui/ui.h"

static Matrix    matrix;
static Encoder   encoder0(PIN_ENC0_CLK, PIN_ENC0_DT, PIN_ENC0_SW);
static Encoder   encoder1(PIN_ENC1_CLK, PIN_ENC1_DT, PIN_ENC1_SW);
static Leds      leds;
static Display   display;
static HID       hid;
static Storage   storage;
static UI        ui;
static AppConfig cfg;

static uint32_t lastUiTick   = 0;
static uint32_t lastIdleTick = 0;

enum class Enc1Mode { Speaker, Mic };
static Enc1Mode enc1Mode      = Enc1Mode::Speaker;
static bool     enc1LongFired = false;

void setup() {
    Serial.begin(115200);
    delay(2000);  // délai fixe — laisse USB composite HID+CDC s'établir
    Serial.println("[main] booting...");

    storage.begin();
    storage.load(cfg);

    matrix.begin();
    encoder0.begin();
    encoder1.begin();

    leds.begin();
    leds.setBrightness(cfg.brightness);
    leds.setLayerColor(cfg.layers[cfg.activeLayer].color);
    leds.show();

    // HID en premier : Keyboard.begin() cause une ré-énumération USB
    // qui détruit l'état SPI si elle arrive après display.begin()
    hid.begin();
    delay(2000);  // attendre la fin de la ré-énumération avant d'init le SPI

    display.begin();
    ui.begin(&cfg);

    Serial.println("[main] ready");
}

void loop() {
    uint32_t now = millis();

    // ── LVGL tick ─────────────────────────────────────────────────────────────
    if (now - lastUiTick >= UI_TICK_MS) {
        lastUiTick = now;
        display.tick();
    }


    display.update();

    // ── Key matrix ────────────────────────────────────────────────────────────
    matrix.scan();
    const Layer& layer = cfg.layers[cfg.activeLayer];
    for (uint8_t i = 0; i < MATRIX_KEY_COUNT; i++) {
        if (matrix.justPressed(i)) {
            uint8_t row = i / MATRIX_COLS, col = i % MATRIX_COLS;
            Serial.print("[key] PRESS r"); Serial.print(row);
            Serial.print(" c"); Serial.print(col);
            Serial.print("  type="); Serial.print(layer.keys[i].type);
            Serial.print(" code=0x"); Serial.println(layer.keys[i].code, HEX);
            hid.pressKey(layer.keys[i]);
            leds.flash(i, 255, 255, 255, 50);
            lastIdleTick = now;
        }
        if (matrix.justReleased(i)) {
            hid.releaseKey(layer.keys[i]);
        }
    }

    // ── Encoder 0 — navigation UI ─────────────────────────────────────────────
    encoder0.update();
    int8_t delta0 = encoder0.getDelta();
    if (delta0 != 0) {
        Serial.print("[enc0] delta="); Serial.println(delta0);
        ui.onEncoderDelta(delta0);
        lastIdleTick = now;
    }
    if (encoder0.buttonPressed()) {
        Serial.println("[enc0] PRESS");
        ui.onEncoderPress();
        lastIdleTick = now;
    }

    // ── Encoder 1 — speaker / mic (long press = toggle mode) ─────────────────
    encoder1.update();
    if (encoder1.buttonHeld(600)) {
        if (!enc1LongFired) {
            enc1LongFired = true;
            enc1Mode = (enc1Mode == Enc1Mode::Speaker) ? Enc1Mode::Mic : Enc1Mode::Speaker;
            bool isMic = (enc1Mode == Enc1Mode::Mic);
            Serial.print("[enc1] mode="); Serial.println(isMic ? "MIC" : "SPEAKER");
            leds.setAll(isMic ? 255 : 0, isMic ? 80 : 100, isMic ? 0 : 255);
            leds.show();
            lastIdleTick = now;
        }
    } else {
        enc1LongFired = false;
    }

    if (encoder1.buttonPressed() && !enc1LongFired) {
        uint16_t code = (enc1Mode == Enc1Mode::Speaker) ? 0xE2 : 0xCF;
        Keyboard.consumerPress((uint16_t)code);
        Keyboard.consumerRelease();
        Serial.println(enc1Mode == Enc1Mode::Speaker ? "[enc1] MUTE SPK" : "[enc1] MUTE MIC");
        lastIdleTick = now;
    }

    int8_t delta1 = encoder1.getDelta();
    if (delta1 != 0) {
        uint16_t code = (delta1 > 0) ? 0xE9 : 0xEA;
        uint8_t steps = abs(delta1);
        for (uint8_t s = 0; s < steps; s++) {
            Keyboard.consumerPress((uint16_t)code);
            Keyboard.consumerRelease();
        }
        Serial.print(enc1Mode == Enc1Mode::Mic ? "[mic] " : "[spk] ");
        Serial.println(delta1 > 0 ? "+" : "-");
        lastIdleTick = now;
    }

    // ── UI update ─────────────────────────────────────────────────────────────
    ui.update();

    // ── Sync LEDs quand le layer change via UI ────────────────────────────────
    if (ui.layerChanged()) {
        leds.setLayerColor(cfg.layers[cfg.activeLayer].color);
        leds.show();
        storage.save(cfg);
    }

    // ── Screen timeout ────────────────────────────────────────────────────────
    if (now - lastIdleTick > SCREEN_TIMEOUT_MS)
        display.setBacklight(30);
    else
        display.setBacklight(255);
}

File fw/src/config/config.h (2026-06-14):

#pragma once

// ─── Display ─────────────────────────────────────────────────────────────────
#define PIN_LCD_CS   9
#define PIN_LCD_SCLK 10
#define PIN_LCD_MOSI 11
#define PIN_LCD_BL   12
#define PIN_LCD_RST  13
#define PIN_LCD_DC   14
#define LCD_WIDTH    240
#define LCD_HEIGHT   320
#define LCD_ROTATION 0   // 0=portrait 240x320, 1=landscape 320x240

// ─── LEDs ─────────────────────────────────────────────────────────────────────
#define PIN_LED_DATA 3
#define LED_COUNT    22
#define LED_DEFAULT_BRIGHTNESS 80

// ─── Key matrix ───────────────────────────────────────────────────────────────
#define MATRIX_COLS 4
#define MATRIX_ROWS 5
#define MATRIX_KEY_COUNT (MATRIX_COLS * MATRIX_ROWS)
#define MATRIX_DEBOUNCE_MS 10

static const uint8_t MATRIX_COL_PINS[MATRIX_COLS] = { 21, 20, 19, 18 };
static const uint8_t MATRIX_ROW_PINS[MATRIX_ROWS] = { 26, 25, 24, 23, 22 };

// ─── Encoders ─────────────────────────────────────────────────────────────────
// Encoder 0 — navigation UI (TODO: verify pins against hardware)
#define PIN_ENC0_CLK 16
#define PIN_ENC0_DT  17
#define PIN_ENC0_SW  2

// Encoder 1 — media / volume
#define PIN_ENC1_CLK 27
#define PIN_ENC1_DT  28
#define PIN_ENC1_SW  29

#define ENCODER_COUNT 2

// ─── Storage ──────────────────────────────────────────────────────────────────
#define CONFIG_FILE "/config.json"
#define MAX_LAYERS  8
#define MAX_LAYER_NAME_LEN 16

// ─── UI ───────────────────────────────────────────────────────────────────────
#define UI_TICK_MS 5
#define SCREEN_TIMEOUT_MS 30000  // dim backlight after 30s idle

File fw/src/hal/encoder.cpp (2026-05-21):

#include "encoder.h"

Encoder* Encoder::_instances[3] = { nullptr, nullptr, nullptr };
uint8_t  Encoder::_count = 0;

static void (*const _isrTable[3])() = {
    Encoder::_isr0,
    Encoder::_isr1,
    Encoder::_isr2,
};

Encoder::Encoder(uint8_t pinClk, uint8_t pinDt, uint8_t pinSw)
    : _pinClk(pinClk), _pinDt(pinDt), _pinSw(pinSw)
{
    _idx = _count < 3 ? _count++ : 0;
    _instances[_idx] = this;
}

void Encoder::begin() {
    pinMode(_pinClk, INPUT_PULLUP);
    pinMode(_pinDt,  INPUT_PULLUP);
    pinMode(_pinSw,  INPUT_PULLUP);
    _lastA = digitalRead(_pinClk);
    attachInterrupt(digitalPinToInterrupt(_pinClk), _isrTable[_idx], CHANGE);
}

void Encoder::update() {
    bool state = digitalRead(_pinSw);
    if (_btnLastState == HIGH && state == LOW) {
        _btnPressTime   = millis();
        _btnPressedFlag = true;
    }
    _btnLastState = state;
}

int8_t Encoder::getDelta() {
    noInterrupts();
    int32_t pos = _position;
    interrupts();
    int8_t delta = (int8_t)(pos - _lastPosition);
    _lastPosition = pos;
    return delta;
}

bool Encoder::buttonPressed() {
    if (_btnPressedFlag) {
        _btnPressedFlag = false;
        return true;
    }
    return false;
}

bool Encoder::buttonHeld(uint32_t ms) {
    return (_btnLastState == LOW) && (millis() - _btnPressTime >= ms);
}

void Encoder::_dispatchISR(uint8_t idx) {
    Encoder* e = _instances[idx];
    if (!e) return;
    bool a = digitalRead(e->_pinClk);
    bool b = digitalRead(e->_pinDt);
    if (a != e->_lastA) {
        e->_position += (a != b) ? 1 : -1;
        e->_lastA = a;
    }
}

void Encoder::_isr0() { _dispatchISR(0); }
void Encoder::_isr1() { _dispatchISR(1); }
void Encoder::_isr2() { _dispatchISR(2); }

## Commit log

2025-08-21 init: first commit
    [ecad.kicad_pcb, ecad.kicad_sch, led.kicad_sch]
2025-09-01 feat(ecad): change pcb size to have constant margin
    [ecad.kicad_pcb, ecad.kicad_sch]
2025-09-17 feat(mcad): add step of kailh switch
    [kailh-switch.step]
2025-09-17 feat(mcad): add step of lcd module
    [lcd-module.step]
2025-09-17 feat(mcad): add dxf of the lcd module to guide pcb design
    [lcd-module-profile.dxf]
2025-09-18 fix(ecad): change pcb format
    [ecad.kicad_pcb, ecad.kicad_sch, led.kicad_sch]
2025-09-21 fix(ecad): replace components to fit new format
    [ecad.kicad_pcb, ecad.kicad_sch]
2025-09-22 fix(mcad): remove lcd-module files to replace by a non breakout tft screen
    [lcd-module-profile.dxf, lcd-module.step]
2025-09-22 feat(ecad): add buttons, fpc connector, and holes to pass flexible pcb of display
    [ecad.kicad_pcb, ecad.kicad_sch]
2025-09-22 doc(ecad): add fpc connector datasheet and catalog
2025-09-24 feat(ecad): hierarchical sheets, add switches net and change some components placement
    [ecad.kicad_pcb, ecad.kicad_sch, leds.kicad_sch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]
2025-09-24 doc(ecad): add display datasheet and use case datasheet
2025-09-25 feat(ecad): route rotary encoders and change some pins arrangement
    [ecad.kicad_pcb, ecad.kicad_sch]
2025-09-26 feat(ecad): change ref of swtiche diode and make the circuitry for the display
    [ecad-B_Cu.gbr, ecad-B_Mask.gbr, ecad-B_Paste.gbr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]
2025-09-28 feat(ecad): general routing
    [ecad.kicad_pcb, ecad.kicad_sch, leds.kicad_sch]
2025-10-08 fix(ecad): change screw placement and rounded corners
    [ecad.kicad_pcb]
2025-10-09 feat(ecad): ws2812b placement and routing
    [ecad.kicad_pcb, ecad.kicad_sch, leds.kicad_sch]
2025-10-12 feat(ecad): gerber update
    [ecad-B_Cu.gbr, ecad-B_Mask.gbr, ecad-B_Paste.gbr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]
2025-10-12 doc(ecad): add folder for pdf export of schematic and pcb
2025-10-12 fix(ecad): change usb connector
    [ecad.kicad_pcb]
2025-10-12 dov(ecad): add usb connector datasheet
2025-10-12 feat(ecad): add missing 3d files to render pcb
    [bourns-pec12r-3220f-s0024.stp, jae-dx07s016ja1.step, worldsemi-ws2812-2020.STEP]
2025-10-12 fix(ecad): change screw holes size
    [ecad.kicad_pcb, ecad.kicad_sch]
2025-11-06 doc(ecad): add encoders datasheet
2025-11-06 fix(ecad): change pcb dimensions
    [ecad.kicad_pcb]
2025-11-12 fix(ecad): change board dimensions
    [ecad.kicad_pcb, ecad.kicad_sch]
2025-11-12 feat(doc): add bom files
2025-11-12 feat(doc): add crystal datasheet and pcb nuts datasheet
2025-11-12 feat(ecad): add pcb nuts on pcb
    [ecad.kicad_sch]
2025-11-13 feat(doc): add 6x6 buttons datasheet and change datasheet name of pcbnuts
2025-11-13 feat(doc): reference all components with lcsc in bom files
2025-11-17 feat(ecad): add graphic logo to pcb
    [ecad.kicad_pcb]
2025-11-18 fix(doc): remove useless bom and replace it with new one
    [bom.xlsx]
2025-11-18 fix(doc): update bom in pdf
2025-11-19 feat(ecad): update gerber to latest version of pcb
    [ecad-B_Cu.gbr, ecad-B_Mask.gbr, ecad-B_Paste.gbr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]
2025-11-22 chore(doc): change documentation structure in a specific folder
    [bom.xlsx]
2026-05-18 feat(fw): scaffold firmware with LVGL, HID, matrix and LED support
    Add complete firmware base for the RP2040 macropad:
    - PlatformIO project (earlephilhower core, TFT_eSPI, LVGL 8.3, ArduinoJson)
    - HAL modules: key matrix 4×5, rotary encoder, WS2812B LEDs, ST7789 display
    - USB HID via arduino-pico native Keyboard (standard + consumer keys)
    - LittleFS + ArduinoJson config storage with 2 default layers
    - LVGL UI scaffold: home screen and settings screen
    - SWD upload via TiGard with documented OpenOCD workarounds
    [config.h, display.cpp, encoder.cpp]
2026-05-18 feat(ecad): update schematics and README with hardware documentation
    - Update KiCad schematics (main, LEDs, switches sub-sheets)
    - Update PCB layout
    - Rewrite README with full hardware specs, GPIO map, architecture
    overview, key config format and commit convention
    [ecad.kicad_pcb, ecad.kicad_sch, leds.kicad_sch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]
2026-05-21 fix(fw): fix matrix scan direction and switch to USB upload
    - Swap matrix scan direction: rows=OUTPUT strobe, cols=INPUT_PULLUP
    (hardware wired opposite to standard convention)
    - Remove TiGard SWD upload config, USB CDC now working via picotool
    - Update CLAUDE.md to reflect USB-only workflow and document
    matrix scan inversion as a known hardware v1 quirk
    - Clean up main.cpp debug heartbeat code left from matrix diagnosis
    [main.cpp, matrix.cpp]
2026-05-21 feat(fw): replace potentiometers with encoders and add volume control
    - Replace PIN_POT_* with PIN_ENC0_*/PIN_ENC1_* in config.h
    - Refactor Encoder class to support multiple instances via static
    ISR dispatch table (up to 3 encoders)
    - Add encoder1 (GPIO27/28/29) mapped to HID consumer volume+/volume-
    and mute on button press
    - encoder0 (GPIO16/17/2) remains navigation/UI encoder
    - Update CLAUDE.md GPIO map accordingly
    [config.h, encoder.cpp, main.cpp]
2026-05-21 fix(ecad): change sur resistor and capacitor value to ajust
    [ecad.kicad_pcb, ecad.kicad_sch]
2026-06-14 refactor(ecad): reorganize footprint library and 3D models
    Replace ecad/3d/ with ecad/3d-models/ (updated model files, JAE connector
    removed, Bourns encoder updated). Add ecad/library.pretty/ with all project
    footprints. Remove old sinhoo-smtso3030ctj local lib. Update fp-lib-table.
    [amphenol-12401948E412A.step, bourns-PEC12R-4225F-S0024.stp, bourns-pec12r-3220f-s0024.stp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]
2026-06-14 fix(ecad): mark R4 as DNP and update zone fill defaults
    R4 set to do-not-place with value corrected to 0.
    Zone fill parameters expanded in project file (thermal relief, hatch, clearance).
    [ecad.kicad_sch]
2026-06-14 chore(ecad): update PCB layout, refresh STEP export and remove stale gerbers
    Gerber files removed — to be regenerated from updated PCB.
    New MCAD STEP export replaces ecad-export.step.
    [ecad-B_Cu.gbr, ecad-B_Mask.gbr, ecad-B_Paste.gbr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]
2026-06-14 fix(fw): replace TFT_eSPI with raw Pico SDK SPI driver for ST7789V2-HSD
    Complete rewrite of display driver using pico-sdk spi_write_blocking (polling,
    no DMA). Custom ST7789V2-HSD init sequence with INVON. Switch to portrait mode
    240x320. SPI frequency reduced to 15 MHz native. TFT_MISO=-1 to avoid pin
    conflict. Filesystem size set to 0.5 MB.
    [config.h, display.cpp]
2026-06-14 feat(fw): add speaker/mic toggle on enc1 long press and redesign UI layer list
    Encoder 1 long press (600ms) toggles between speaker and mic mode, LEDs
    indicate the active mode. Short press mutes the active device.
    UI replaced with a single-screen layer list: header with active layer name,
    scrollable list with color band and active indicator per layer, footer with
    navigation hints. layerChanged() replaces onLayerChanged() callback. Layer
    switch via encoder press syncs LEDs and persists config.
    USB init order fixed: hid.begin() moved before display.begin() to prevent
    SPI corruption during Keyboard USB re-enumeration.
    [main.cpp]
2026-06-14 doc: simplify and update README
    Remove verbose GPIO map, commit convention and contributing sections.
    Fix display spec (240x320 portrait, ST7789V2-HSD), replace ADC pot GPIO
    entries with encoder 1 pins, update architecture tree, fix flash commands
    (pico env only). Add Controls section for encoder behaviour. Update roadmap.
